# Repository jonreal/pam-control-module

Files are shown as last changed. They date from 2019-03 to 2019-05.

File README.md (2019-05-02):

# pam-control-module
Hardware/software project for pneumatic artificial muscles (PAM) control module.

After downloading, move libraries/Pam directory to local Arduino libraries/ directory. (0r symlink them).
Flash Arduino with example.ino to run the example code. You will see LEDs light up in sequential order if succesful.

NOTE: current hardware version is missing pulldown resistors on digital input
pins -- this will be fixed in the next version.

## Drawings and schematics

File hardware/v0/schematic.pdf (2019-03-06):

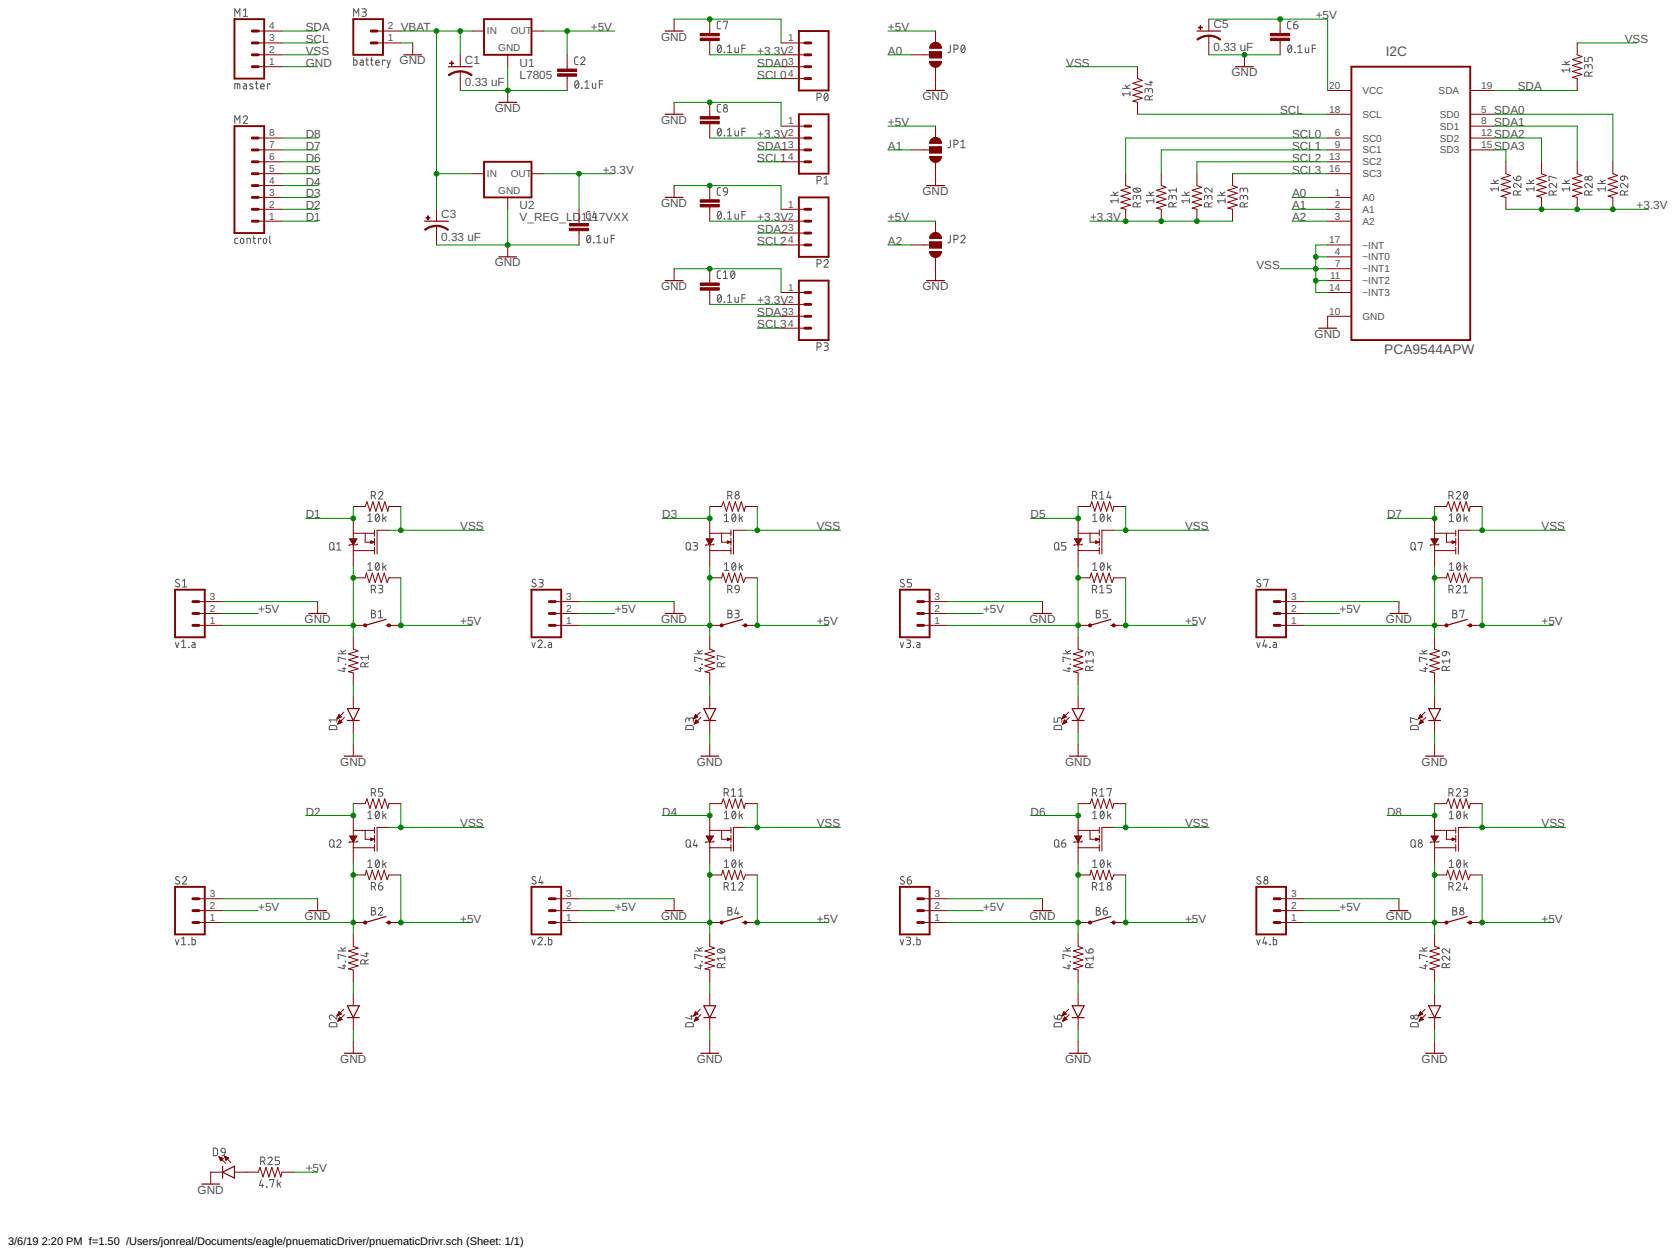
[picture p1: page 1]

3/6/19 2:20 PM f=1.50 /Users/jonreal/Documents/eagle/pnuematicDriver/pnuematicDrivr.sch (Sheet: 1/1)

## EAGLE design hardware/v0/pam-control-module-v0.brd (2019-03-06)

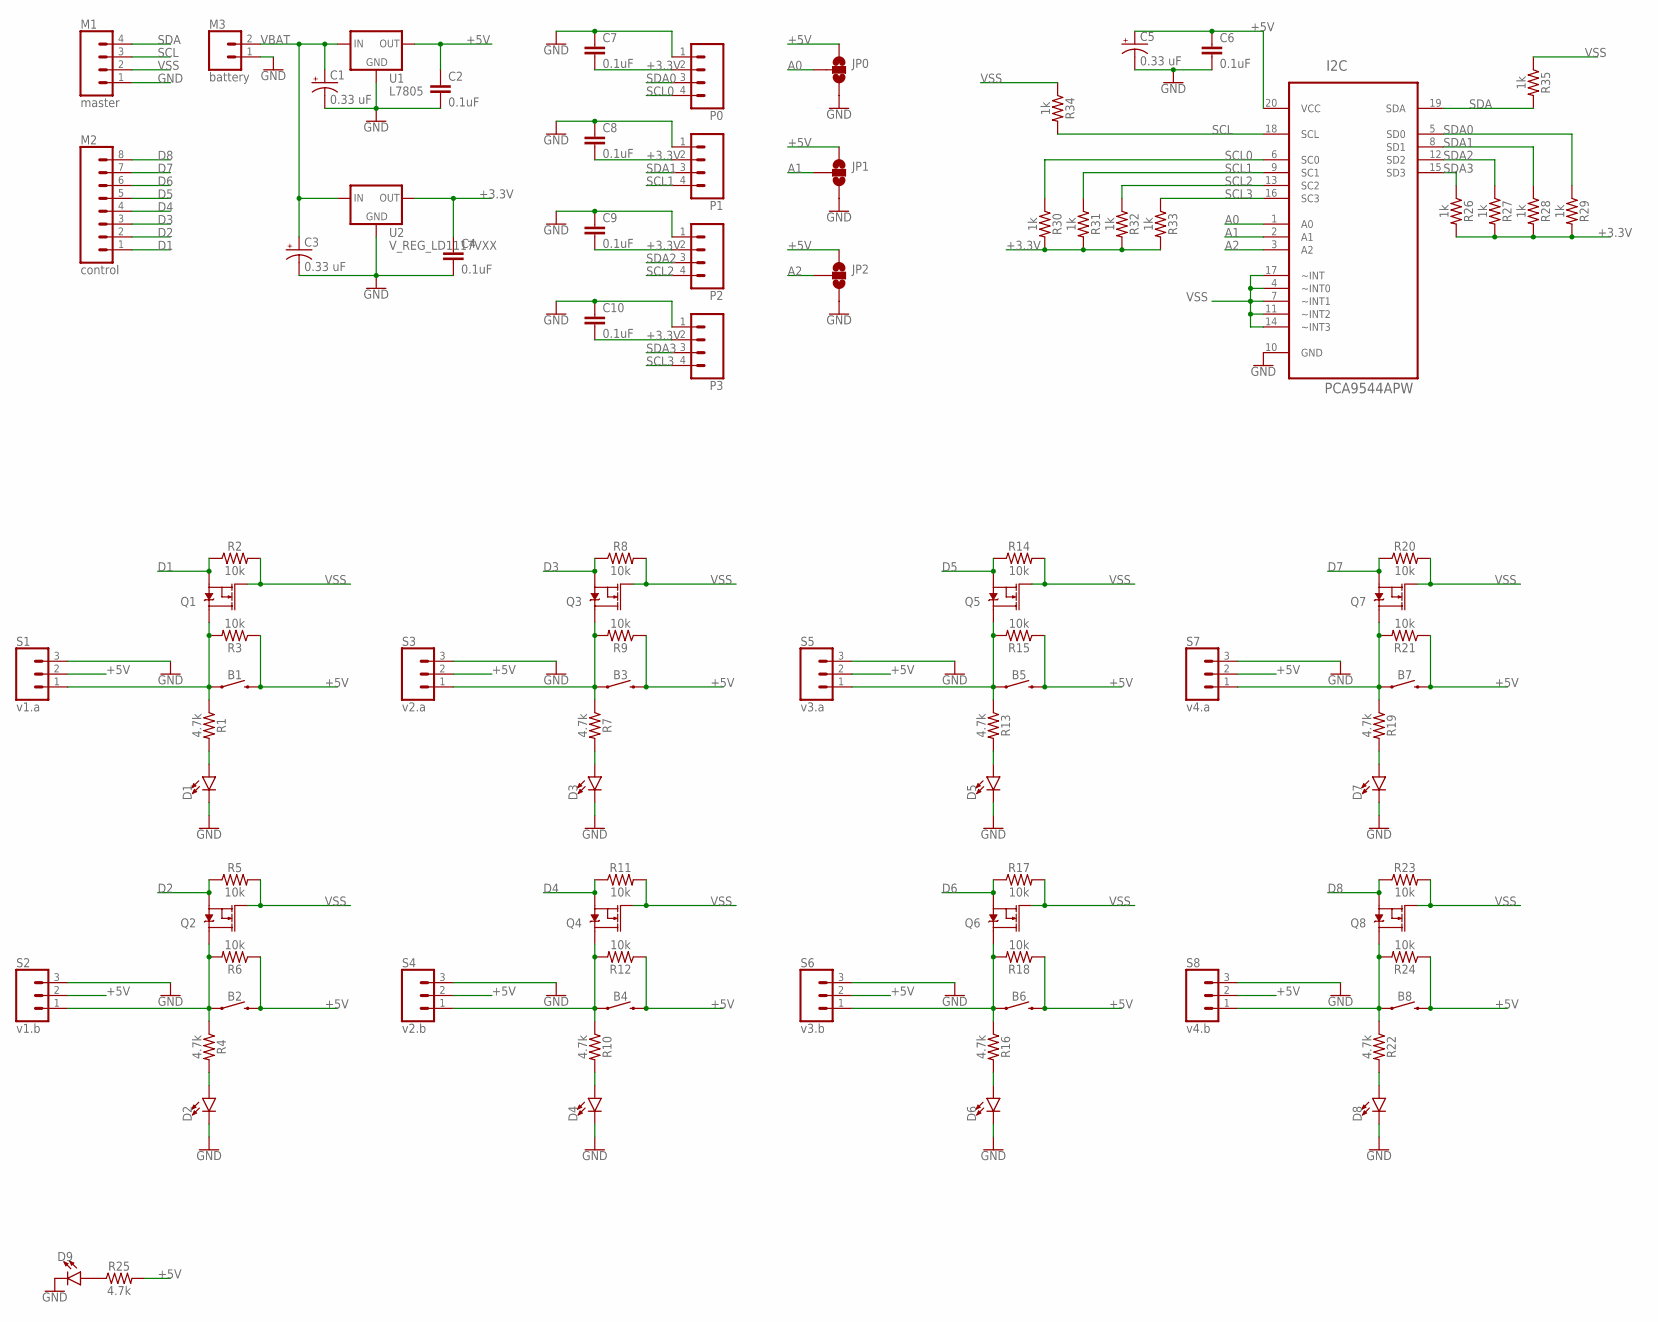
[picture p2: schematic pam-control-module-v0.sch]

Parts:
B1, B2, B3, B4, B5, B6, B7, B8: MOMENTARY-SWITCH-SPST-PTH-6.0MM; TACTILE_SWITCH_PTH_6.0MM
C1, C3, C5: 0.33 uF; E2-5
C2, C4, C6, C7, C8, C9, C10: 0.1uF; CAP-PTH-SMALL-KIT
D1, D2, D3, D4, D5, D6, D7, D8, D9: LED3MM; LED_3MM
I2C: PCA9544APW; SOP65P640X120-20N
JP0, JP1, JP2: JUMPER-SMT_3_NO_SILK; SMT-JUMPER_3_NO_SILK
M1: master; 1X04
M2: control; 1X08
M3: battery; 1X02
P0, P1, P2, P3: CONN_04; 1X04
Q1, Q2, Q3, Q4, Q5, Q6, Q7, Q8: MOSFET-NCH-BSS138; SOT23-3
R1, R4, R7, R10, R13, R16, R19, R22, R25: 4.7k; AXIAL-0.3
R2, R3, R5, R6, R8, R9, R11, R12, R14, R15, R17, R18, R20, R21, R23, R24: 10k; AXIAL-0.3
R26, R27, R28, R29, R30, R31, R32, R33, R34, R35: 1k; AXIAL-0.3
S1: v1.a; 1X03
S2: v1.b; 1X03
S3: v2.a; 1X03
S4: v2.b; 1X03
S5: v3.a; 1X03
S6: v3.b; 1X03
S7: v4.a; 1X03
S8: v4.b; 1X03
U1: L7805; 78XXL
U2: V_REG_LD1117VXX; 78XXL

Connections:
+3.3V: C4.1, C7.2, C8.2, C9.2, C10.2, P0.2, P1.2, P2.2, P3.2, R26.P$2 (2), R27.P$2 (2), R28.P$2 (2), R29.P$2 (2), R30.P$2 (2), R31.P$2 (2), R32.P$2 (2), R33.P$2 (2), U2.GND (OUT)
+5V: B1.3 (2), B2.3 (2), B3.3 (2), B4.3 (2), B5.3 (2), B6.3 (2), B7.3 (2), B8.3 (2), C2.1, C5.+, C6.1, I2C.20 (VCC), JP0.1, JP1.1, JP2.1, R3.P$1 (1), R6.P$1 (1), R9.P$1 (1), R12.P$1 (1), R15.P$1 (1), R18.P$1 (1), R21.P$1 (1), R24.P$1 (1), R25.P$2 (2), S1.2, S2.2, S3.2, S4.2, S5.2, S6.2, S7.2, S8.2, U1.OUT
A0: I2C.1 (A0), JP0.2
A1: I2C.2 (A1), JP1.2
A2: I2C.3 (A2), JP2.2
D1: M2.1, Q1.2 (S), R2.P$1 (1)
D2: M2.2, Q2.2 (S), R5.P$1 (1)
D3: M2.3, Q3.2 (S), R8.P$1 (1)
D4: M2.4, Q4.2 (S), R11.P$1 (1)
D5: M2.5, Q5.2 (S), R14.P$1 (1)
D6: M2.6, Q6.2 (S), R17.P$1 (1)
D7: M2.7, Q7.2 (S), R20.P$1 (1)
D8: M2.8, Q8.2 (S), R23.P$1 (1)
GND: C1.-, C2.2, C3.-, C4.2, C5.-, C6.2, C7.1, C8.1, C9.1, C10.1, D1.K (C), D2.K (C), D3.K (C), D4.K (C), D5.K (C), D6.K (C), D7.K (C), D8.K (C), D9.K (C), I2C.10 (GND), JP0.3, JP1.3, JP2.3, M1.1, M3.1, P0.1, P1.1, P2.1, P3.1, S1.3, S2.3, S3.3, S4.3, S5.3, S6.3, S7.3, S8.3, U1.GND, U2.IN (GND)
unnamed: D1.A, R1.P$2 (2)
unnamed: D2.A, R4.P$2 (2)
unnamed: D3.A, R7.P$2 (2)
unnamed: D4.A, R10.P$2 (2)
unnamed: B2.1, Q2.3 (D), R4.P$1 (1), R6.P$2 (2), S2.1
unnamed: D5.A, R13.P$2 (2)
unnamed: D6.A, R16.P$2 (2)
unnamed: D7.A, R19.P$2 (2)
unnamed: D8.A, R22.P$2 (2)
unnamed: D9.A, R25.P$1 (1)
unnamed: B4.1, Q4.3 (D), R10.P$1 (1), R12.P$2 (2), S4.1
unnamed: B6.1, Q6.3 (D), R16.P$1 (1), R18.P$2 (2), S6.1
unnamed: B8.1, Q8.3 (D), R22.P$1 (1), R24.P$2 (2), S8.1
unnamed: B7.1, Q7.3 (D), R19.P$1 (1), R21.P$2 (2), S7.1
unnamed: B5.1, Q5.3 (D), R13.P$1 (1), R15.P$2 (2), S5.1
unnamed: B3.1, Q3.3 (D), R7.P$1 (1), R9.P$2 (2), S3.1
unnamed: B1.1, Q1.3 (D), R1.P$1 (1), R3.P$2 (2), S1.1
SCL: I2C.18 (SCL), M1.3, R34.P$2 (2)
SCL0: I2C.6 (SC0), P0.4, R30.P$1 (1)
SCL1: I2C.9 (SC1), P1.4, R31.P$1 (1)
SCL2: I2C.13 (SC2), P2.4, R32.P$1 (1)
SCL3: I2C.16 (SC3), P3.4, R33.P$1 (1)
SDA: I2C.19 (SDA), M1.4, R35.P$2 (2)
SDA0: I2C.5 (SD0), P0.3, R29.P$1 (1)
SDA1: I2C.8 (SD1), P1.3, R28.P$1 (1)
SDA2: I2C.12 (SD2), P2.3, R27.P$1 (1)
SDA3: I2C.15 (SD3), P3.3, R26.P$1 (1)
VBAT: C1.+, C3.+, M3.2, U1.IN, U2.OUT (IN)
VSS: I2C.4 (~INT0), I2C.7 (~INT1), I2C.11 (~INT2), I2C.14 (~INT3), I2C.17 (~INT), M1.2, Q1.1 (G), Q2.1 (G), Q3.1 (G), Q4.1 (G), Q5.1 (G), Q6.1 (G), Q7.1 (G), Q8.1 (G), R2.P$2 (2), R5.P$2 (2), R8.P$2 (2), R11.P$2 (2), R14.P$2 (2), R17.P$2 (2), R20.P$2 (2), R23.P$2 (2), R34.P$1 (1), R35.P$1 (1)

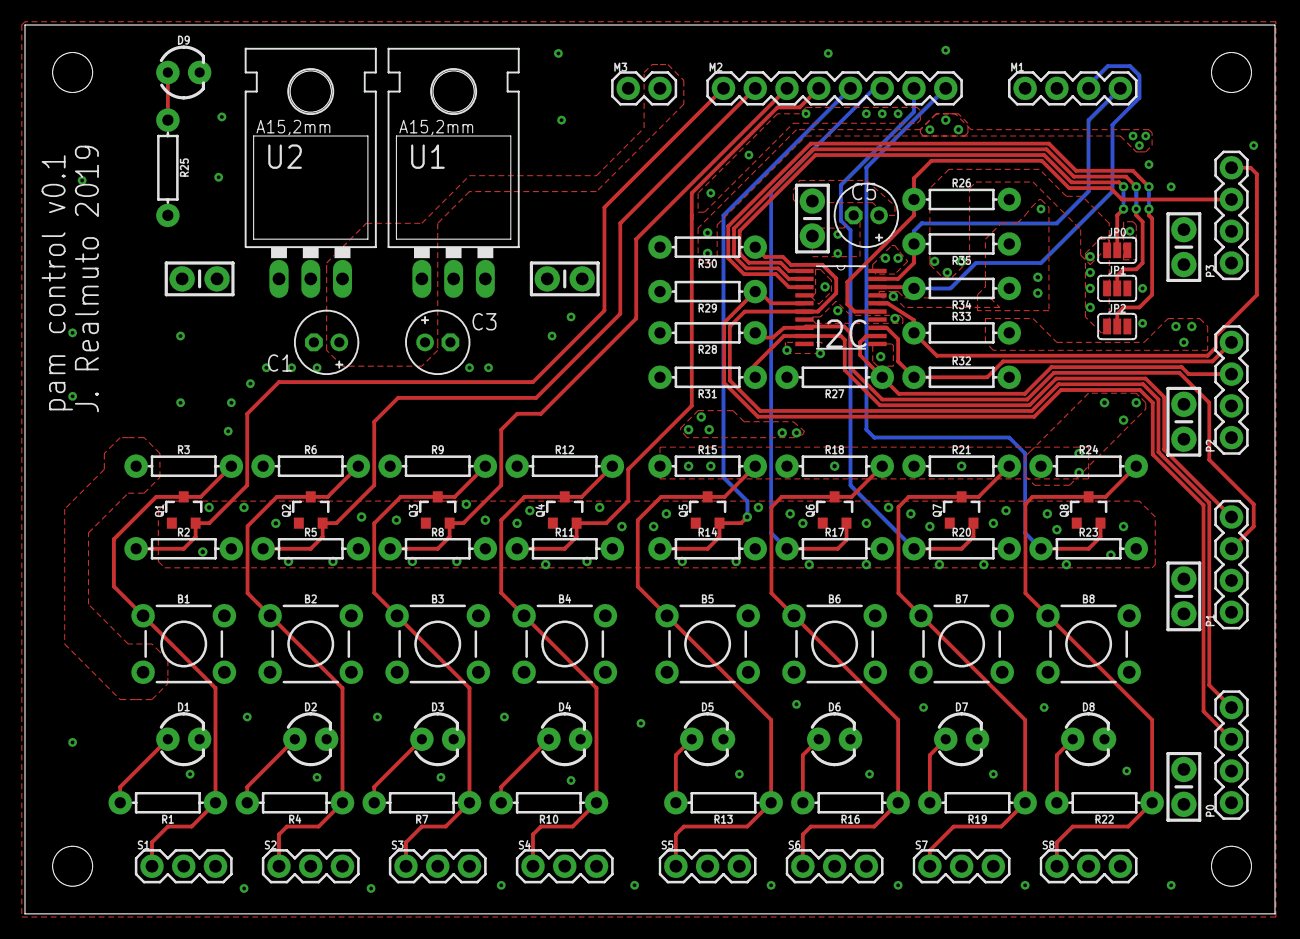
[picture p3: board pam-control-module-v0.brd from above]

Board: 2 copper layers, 100.0 x 71.1 mm, 91 parts (0 on the bottom side), 43 nets.

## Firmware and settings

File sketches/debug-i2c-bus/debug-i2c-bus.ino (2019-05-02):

#include "Pam.h"

// Create global PAM (pneumatic artificial muscle) controller
Pam Pam(0x77); // argument is i2c address

// Other globals
long t = 0;  // loop counter
float p[4];  // array of pressures (one for each channel)

void setup() {

  Serial.begin(9600);

  // Init PAM
  Pam.begin();

  // Set valve pins for each PAM channel
  Pam.setupChannel(0, 2, 3); // arguments: ch, a_pin, b_pin
  Pam.setupChannel(1, 4, 5);
  Pam.setupChannel(2, 6, 7);
  Pam.setupChannel(3, 8, 9);

  Pam.debugBus();
}

void loop() {
}

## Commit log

2019-03-06 First commit added relevent files
    [pam-control-module-v0.brd, pam-control-module-v0.sch]
2019-03-06 Added pdf of schematic

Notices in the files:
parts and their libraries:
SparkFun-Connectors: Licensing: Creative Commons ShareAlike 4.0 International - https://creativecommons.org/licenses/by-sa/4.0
